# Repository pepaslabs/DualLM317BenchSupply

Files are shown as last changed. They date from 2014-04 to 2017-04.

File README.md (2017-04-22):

DualLM317BenchSupply
====================

A simple adjustable voltage, current limited bench power supply using two LM317 regulators, designed in KiCAD.

Features:

* Voltage is variable, using a 10-turn pot.
* Current is limited in 6 steps (13mA, 25mA, 63mA, 125mA, 250mA, 500mA).
* A current-limit bypass switch allows for more than 500mA.  Be careful not to exceed 1.5A.  This is the "trust me, I know what I'm doing" switch.
* Footprints included for both 2.1x5.5mm and 2.5x5.5mm DC barrel jacks (the two sizes you are most likely to have on hand).
* Modifications possible by populating the board with alternate parts

Latest Schematic:

[View schematic as PDF](https://github.com/pepaslabs/DualLM317BenchSupply/raw/master/DualLM317BenchSupply_schematic.pdf).

## License

Parts which I have created are released under the [MIT License](http://opensource.org/licenses/MIT).  Parts which I have modified are subject to their original license.

## Board Revision v2

Revision 2 of the boards are being beta tested amongst some friends.  I'll probably put it up on tindie.com soon!

* KiCAD files: https://github.com/pepaslabs/DualLM317BenchSupply/archive/v2.0.zip
* Bill Of Materials: https://docs.google.com/spreadsheets/d/1UEHeVoLBXWML7s4iypZqZUHYBSBsEXaSeRBIaHcoUhg/edit?usp=sharing
* Assembly Instructions: https://www.evernote.com/shard/s301/sh/98922a1c-4789-4eff-8265-b3d52353a5f1/38aa0f58f0495949719a24fac0aefa83

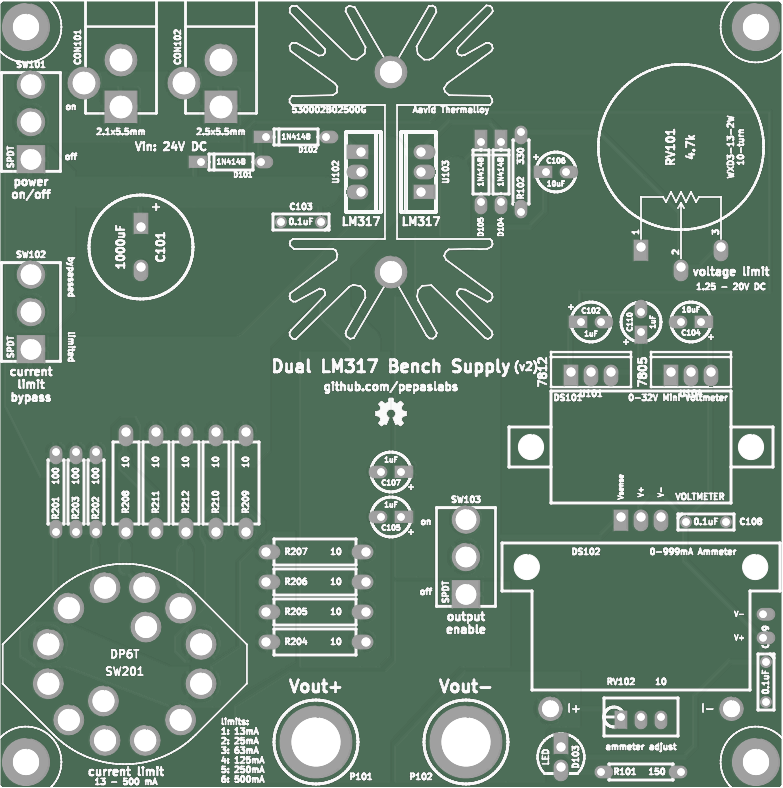
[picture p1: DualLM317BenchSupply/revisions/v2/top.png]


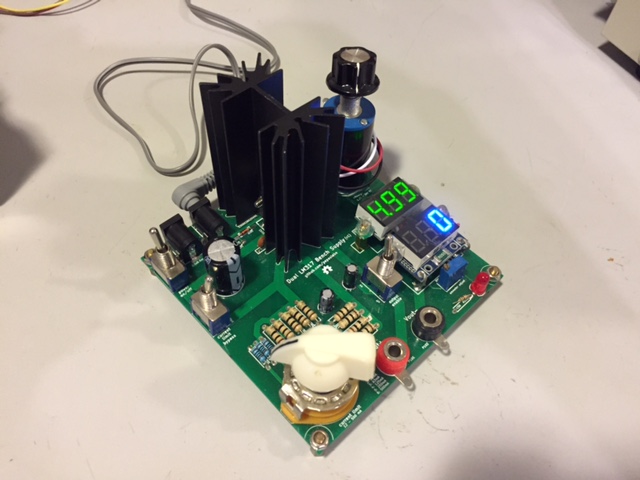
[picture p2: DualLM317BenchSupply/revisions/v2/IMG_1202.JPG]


## Board Revision v1

A run of five v1 boards was ordered, but they suffered from a manufacturing defect which shorted a pad to ground.  Thus, this revision was never publicly for sale.

* KiCAD files: https://github.com/pepaslabs/DualLM317BenchSupply/archive/v1.0.zip
* Bill Of Materials: https://docs.google.com/spreadsheets/d/1L0ausNb0WpCJjKkbzb2hiCHUUvhVTbAR-jT5hPuG_W0/edit?usp=sharing

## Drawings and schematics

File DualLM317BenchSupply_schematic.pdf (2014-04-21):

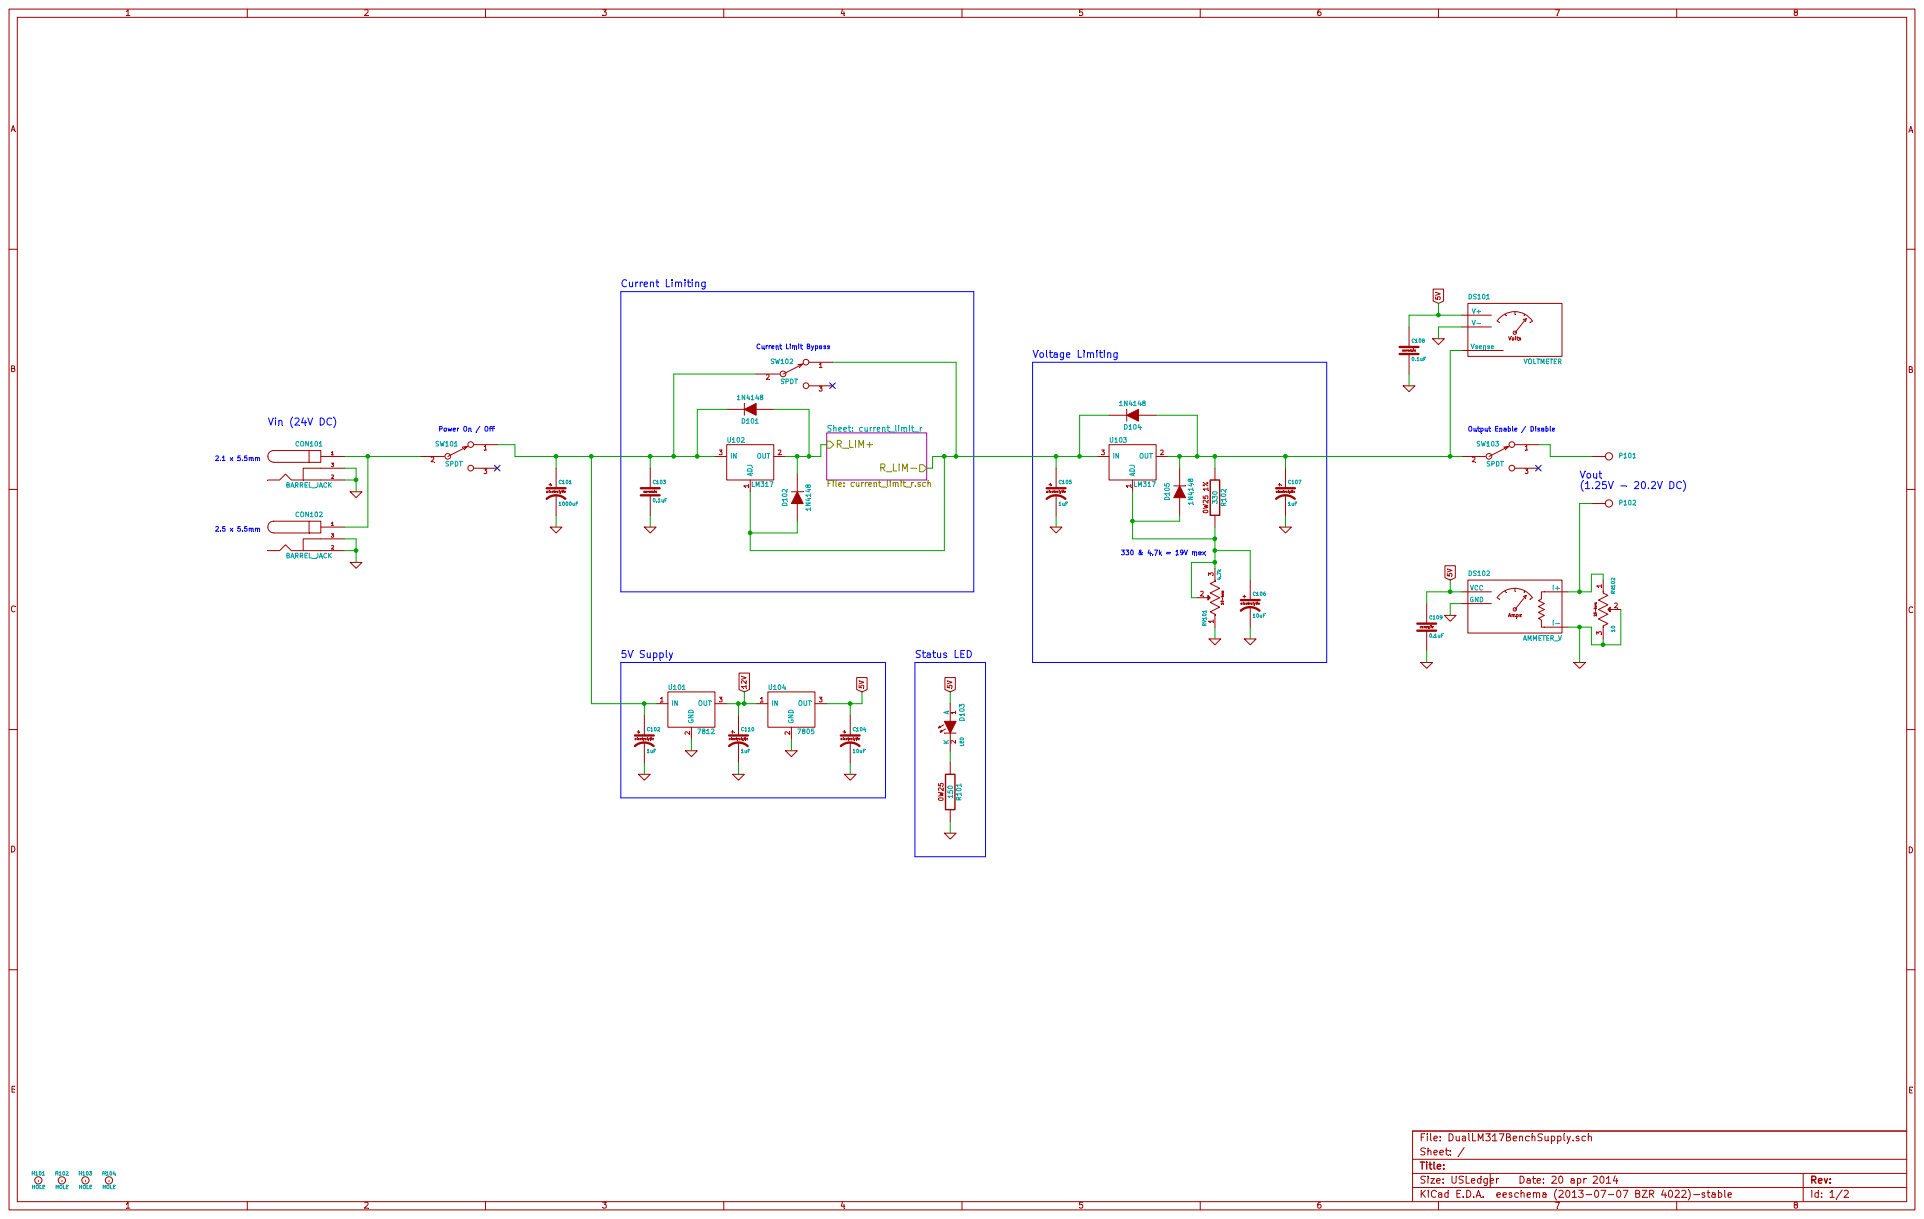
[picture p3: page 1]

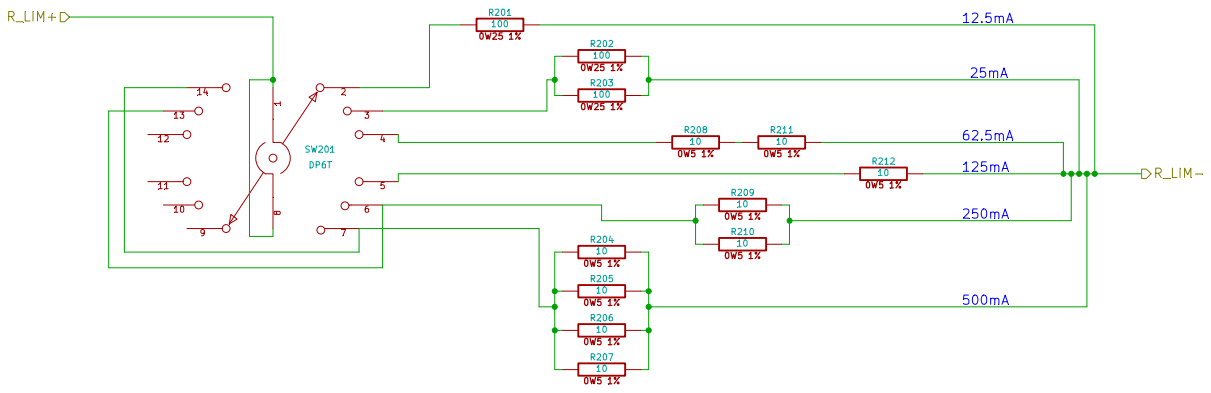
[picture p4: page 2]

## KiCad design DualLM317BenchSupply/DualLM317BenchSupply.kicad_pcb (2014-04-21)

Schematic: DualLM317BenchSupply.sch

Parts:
C101: 1000uF
C102, C105, C107, C110: 1uF
C103, C108, C109: 0.1uF
C104, C106: 10uF
CON101, CON102: BARREL_JACK
D101, D102, D104, D105: 1N4148
D103: LED
DS101: VOLTMETER
DS102: AMMETER_V
H101, H102, H103, H104: HOLE
P101: Vout+
P102: Vout-
R101: 150
R102: 330
RV101: 4.7k
RV102: 10
SW101, SW102, SW103: SPDT
U101: 7812
U102, U103: LM317
U104: 7805

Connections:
5V: C104.1, C108.1, C109.1, D103.1 (A), DS101.2, DS102.3, U104.3 (OUT)
12V: C110.1, U101.3 (OUT), U104.1 (IN)
/current_limit_r/R_LIM+: D101.1 (A), D102.2 (K), U102.2 (OUT); also elsewhere on the board
/current_limit_r/R_LIM-: C105.1, D102.1 (A), D104.2 (K), SW102.1, U102.1 (ADJ), U103.3 (IN); also elsewhere on the board
GND: C101.2, C102.2, C103.2, C104.2, C105.2, C106.2, C107.2, C108.2, C109.2, C110.2, CON101.2, CON101.3, CON102.2, CON102.3, DS101.3, DS102.2, DS102.4, R101.2, RV101.1, RV102.2, RV102.3, U101.2 (GND), U104.2 (GND)
unnamed: C107.1, D104.1 (A), D105.2 (K), DS101.1, R102.1, SW103.2, U103.2 (OUT)
unnamed: C106.1, D105.1 (A), R102.2, RV101.2, RV101.3, U103.1 (ADJ)
unnamed: P101.1, SW103.1
unnamed: DS102.1, P102.1, RV102.1
unnamed: D103.2 (K), R101.1
unnamed: CON101.1, CON102.1, SW101.2
unnamed: C101.1, C102.1, C103.1, D101.2 (K), SW101.1, SW102.2, U101.1 (IN), U102.3 (IN)

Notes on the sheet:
Current Limit Bypass
Vout (1.25V - 20.2V DC)
Vin (24V DC)
Voltage Limiting
Current Limiting
Status LED
Power On / Off
Output Enable / Disable
330 & 4.7k = 19V max
5V Supply
2.1 x 5.5mm
2.5 x 5.5mm

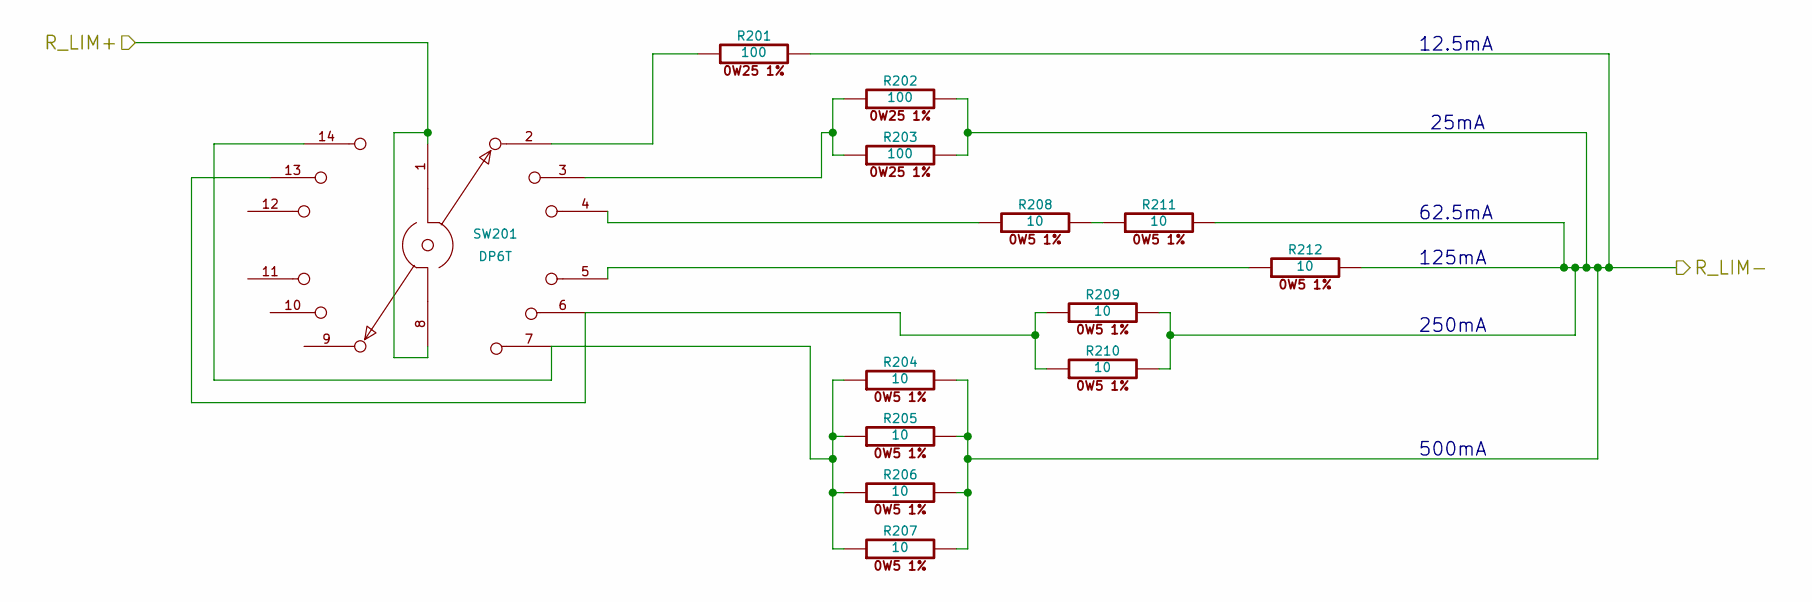
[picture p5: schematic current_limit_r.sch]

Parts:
R201, R202, R203: 100
R204, R205, R206, R207, R208, R209, R210, R211, R212: 10
SW201: DP6T

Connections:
/current_limit_r/R_LIM+: SW201.1, SW201.8; also elsewhere on the board
/current_limit_r/R_LIM-: R201.2, R202.2, R203.2, R204.2, R205.2, R206.2, R207.2, R209.2, R210.2, R211.2, R212.2; also elsewhere on the board
unnamed: R209.1, R210.1, SW201.6, SW201.13
unnamed: R204.1, R205.1, R206.1, R207.1, SW201.7, SW201.14
unnamed: R208.2, R211.1
unnamed: R212.1, SW201.5
unnamed: R208.1, SW201.4
unnamed: R201.1, SW201.2
unnamed: R202.1, R203.1, SW201.3

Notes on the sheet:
12.5mA
25mA
62.5mA
125mA
250mA
500mA

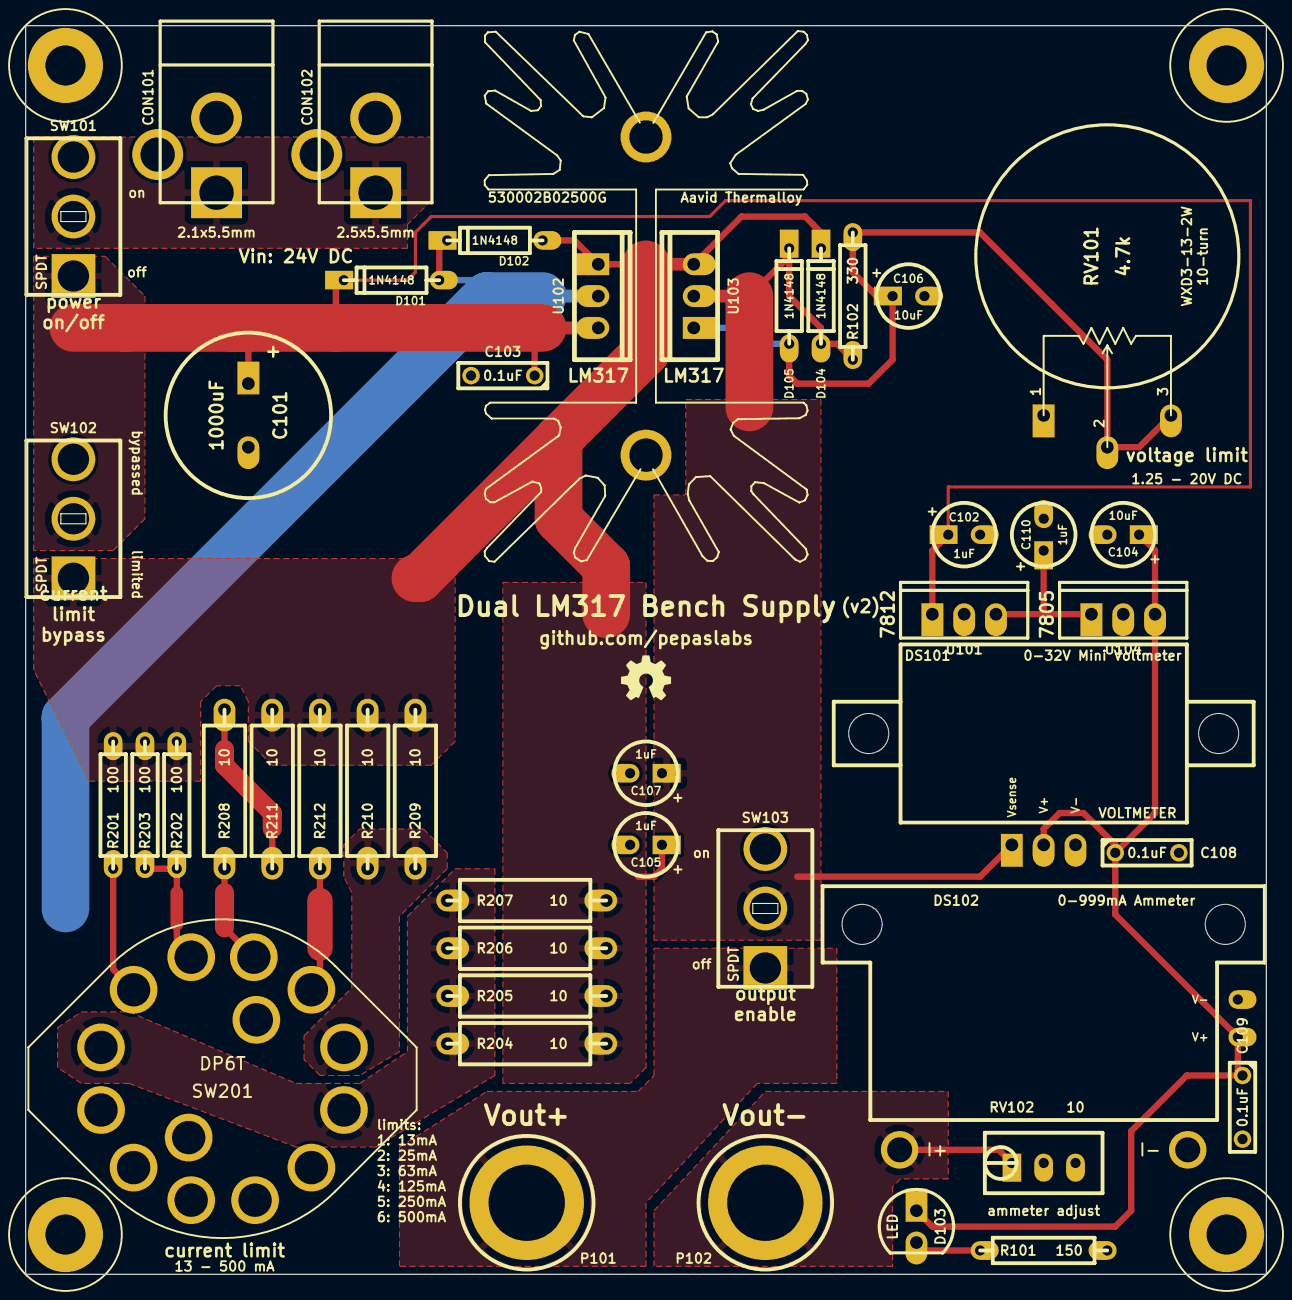
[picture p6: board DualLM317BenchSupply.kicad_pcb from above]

Board: 2 copper layers, 99.1 x 99.7 mm, 50 parts (0 on the bottom side), 19 nets.

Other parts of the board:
H***: 530002B02500G

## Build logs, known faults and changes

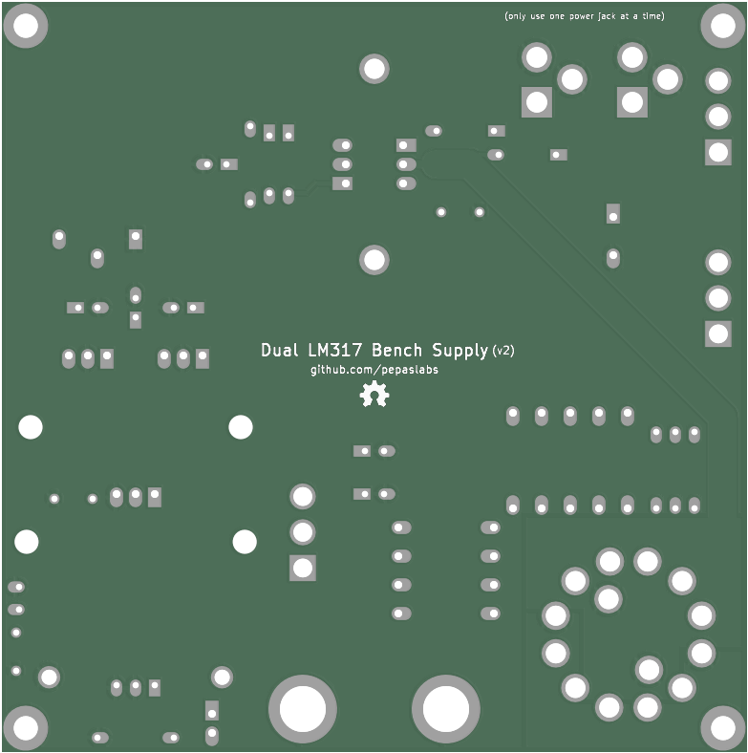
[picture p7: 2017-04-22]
DualLM317BenchSupply/revisions/v2/bottom.png

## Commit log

2014-03-01 Initial project creation
    [DualLM317BenchSupply.kicad_pcb, DualLM317BenchSupply.sch]
2014-03-01 basic schematic laid out.
2014-03-16 updating design to use 6 position switch to select current limiting resistor.
    [DualLM317BenchSupply.sch, current_limit_r.sch]
2014-03-16 adding input / output switches, revising schematic parts.
    [DualLM317BenchSupply.sch, current_limit_r.sch]
2014-03-16 adding voltmeter and ammeter
    [DualLM317BenchSupply.sch]
2014-03-16 annotating parts. adding printout of schematic.
    [DualLM317BenchSupply.sch, current_limit_r.sch]
2014-03-16 adding voltmeter / ammeter
    [DualLM317BenchSupply.sch, current_limit_r.sch]
2014-03-16 updating printout
2014-03-17 revising protection diodes
    [DualLM317BenchSupply.sch, current_limit_r.sch]
2014-03-17 adding connectors and heatsinks libs
    [DualLM317BenchSupply.kicad_pcb, DualLM317BenchSupply.sch, current_limit_r.sch]
2014-03-17 updating switch
    [DualLM317BenchSupply.sch, current_limit_r.sch]
2014-03-17 updating parts
    [DualLM317BenchSupply.kicad_pcb, DualLM317BenchSupply.sch, current_limit_r.sch]
2014-03-17 updating switches, capacitors, and LEDs
    [DualLM317BenchSupply.kicad_pcb, DualLM317BenchSupply.sch, current_limit_r.sch]
2014-03-18 reconfiguring protection diodes
    [DualLM317BenchSupply.sch, current_limit_r.sch]
2014-03-18 moving status LED to 5V rail. starting initial layout.
    [DualLM317BenchSupply.kicad_pcb, DualLM317BenchSupply.sch]
2014-03-18 updating schematic
    [DualLM317BenchSupply.sch]
2014-03-20 reconfiguring ammeter to be low-side, not high-side.
    [DualLM317BenchSupply.sch, current_limit_r.sch]
2014-03-21 switching to voltmeter based on real ground, not Vout- (introduced too much error into the ammeter)
    [DualLM317BenchSupply.sch, current_limit_r.sch]
2014-03-21 updating schematic printout.
2014-03-22 specifying 1% for current limiting resistors (lower temp co). also, moving 10R resistors to 1/2 watt.
    [DualLM317BenchSupply.sch, current_limit_r.sch]
2014-03-22 working on board layout
    [DualLM317BenchSupply.kicad_pcb, DualLM317BenchSupply.sch]
2014-03-23 updating resistor footprint filters
2014-03-23 working on layout of current limit selector switch resistors.
    [DualLM317BenchSupply.kicad_pcb]
2014-03-23 adding second dc jack
    [DualLM317BenchSupply.sch, current_limit_r.sch]
2014-03-23 adding mounting holes to schematic
    [DualLM317BenchSupply.kicad_pcb, DualLM317BenchSupply.sch, current_limit_r.sch]
2014-03-23 dc jacks
    [DualLM317BenchSupply.kicad_pcb]
2014-03-23 working on input layout
    [DualLM317BenchSupply.kicad_pcb, DualLM317BenchSupply.sch]
2014-03-23 working on current limit switch layout
    [DualLM317BenchSupply.kicad_pcb]
2014-03-23 working on layout
    [DualLM317BenchSupply.kicad_pcb, DualLM317BenchSupply.sch, current_limit_r.sch]
2014-03-23 pulling in diodes lib
    [DualLM317BenchSupply.kicad_pcb, DualLM317BenchSupply.sch]
2014-03-23 updating layout
    [DualLM317BenchSupply.kicad_pcb]
2014-03-23 adding voltmeter and potentiometer to layout
    [DualLM317BenchSupply.kicad_pcb, DualLM317BenchSupply.sch]
2014-03-24 adding ammeter footprint
    [DualLM317BenchSupply.kicad_pcb]
2014-03-28 correcting pads for ammeter and running traces to it
    [$DualLM317BenchSupply.sch, DualLM317BenchSupply.kicad_pcb, current_limit_r.sch]
2014-03-28 adding caps for meters
    [$DualLM317BenchSupply.sch, DualLM317BenchSupply.kicad_pcb, DualLM317BenchSupply.sch]
2014-03-28 tweaked board labels and created v1 gerbers
    [DualLM317BenchSupply-B_Cu.gbl, DualLM317BenchSupply-B_Mask.gbs, DualLM317BenchSupply-B_SilkS.gbo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]
2014-03-28 adding back silkscreen
    [DualLM317BenchSupply.kicad_pcb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]
2014-04-19 thinning cap trace for solderability
    [DualLM317BenchSupply.kicad_pcb]
2014-04-19 thinning traces for solderability
    [DualLM317BenchSupply.kicad_pcb]
2014-04-19 thinning out traces for solderability
    [DualLM317BenchSupply.kicad_pcb]
2014-04-19 bumping board version. more trace thinning.
    [DualLM317BenchSupply.kicad_pcb]
2014-04-19 updating gerbers
    [DualLM317BenchSupply-B_Cu.gbl, DualLM317BenchSupply-B_Mask.gbs, DualLM317BenchSupply-B_SilkS.gbo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]
2014-04-20 updating pdf printout
2014-04-20 adding 7812 before the 7805 to distribute the thermal load (a 7812 is cheaper than a heatsink :).
    [DualLM317BenchSupply.kicad_pcb, DualLM317BenchSupply.sch, current_limit_r.sch]
2014-04-21 using fills instead of traces for high current areas
    [DualLM317BenchSupply.kicad_pcb]
2014-04-21 more tweaks to fills
    [DualLM317BenchSupply-B_Cu.gbl, DualLM317BenchSupply-B_Mask.gbs, DualLM317BenchSupply-B_SilkS.gbo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]
2014-04-21 zipping up gerbers for v2
2014-04-21 updating barrell jack footprints
    [DualLM317BenchSupply-B_Cu.gbl, DualLM317BenchSupply-B_Mask.gbs, DualLM317BenchSupply-B_SilkS.gbo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]
2017-04-22 adding board shots
